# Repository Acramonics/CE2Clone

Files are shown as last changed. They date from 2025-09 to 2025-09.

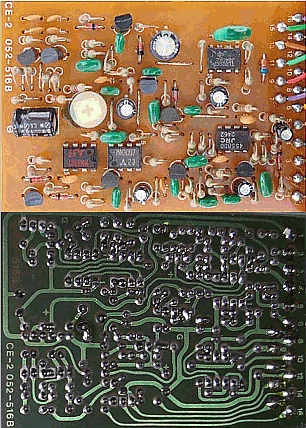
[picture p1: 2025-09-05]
Schematics/boss-ce2-board.webp

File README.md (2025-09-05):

Boss CE-2 Clone
===============

**Andrew Martin, September 2025**

*Please note that I don't yet have this working! I believe this is a result of a bad clone MN3007!*

Introduction
------------

The Boss CE-2 is one of the best-known chorus pedals around and there
have been several clones with and without modifications. In the
`Schematics` folder, there is a collection of freely-available
schematics and information while the `Analysis` folder contains some
information on chorus effects and a full analysis of the workings of
the Boss CE-2 from ElectroSmash.

The `kicad` folder contains my schematic for a clone which is
essentially the original version with the 'anti-tic' modification and
with 2N5088 transistors throughout. Within that are two sub-folders,
`V0.1` and `V1.1`. *Do not use V0.1* - this was an erroneous design
where the inputs to the RC4558 (U1) were swapped by mistake!

V1.1 is my first correct layout with (optional) LED and (bypassable)
-ve power supply resistor and diode (see some of the schamatics and
analyses for references to this). It is a very tightly packed 57x87mm
board.

V1.2 is the current version in which the PCB layout is inspired by the
one used by Azure. This one contains the (bypassable) -ve power supply
resistor and diode, but not the LED as the intention is to use it with
my FootSwitch board. This is a somewhat less tightly packed board
(73x83mm) with wider (1mm) tracks; there was notable resistance
with the narrow tracks of V1.1.

Kicad
-----

The design uses my own symbol for the 2N5088 which is in my
`ACRM_KiCad_Libs` library.

The rate and depth pots (both are 100K linear pots) are not included
in the schematic - instead there are just positions for Molex KK254
connectors. If you wish, you can omit the connectors and wire direct
to the board.

Testing
-------

Note that the MN3007/MN3101 need a negative power supply, so it is
correct that the GND pin (Pin 1) on both is connected to the +9VA rail
and the input voltage VDD pin (Pin 3 on the MN3101 and Pin 5 on the
MN3007) is connected to GND.

Faulty (apparently they are very static sensitive, but I haven't seen
that), or bad clone, MN3101s are common, so it's a good idea to check
that it's working properly. There are three things to check in the circuit:

- Connect a meter across pins 1 (your black test lead) and 3 (red test
  lead) to find the power supply voltage you are getting. This should
  be showing a value of around -8.5V. Make sure you note what the
  exact voltage is.

- Connect a meter across pins 1 (black test lead) and 8 (VGG_OUT, red
  test lead). This should read VDD*14/15, so if your VDD was -8.5, you
  should be obtaining -7.93V.

- Put a 'scope on pin 2 (CP1) and then on pin 4 (CP2). You should see
  a (roughly) square wave form that expands and contracts. The amount
  of variation changes with the depth pot and the rate with the rate
  pot.

If those tests all work, then your MN3101 is working correctly.

Setup
-----

Turn the **Rate** pot fully **anti-clockwise** (minimum rate) and the
**Depth** pot fully **clockwise** (maximum depth).

Use a signal generator to feed a 200Hz, +3dBm sine signal into the
input. This comes from the setup information I have seen online.

+3dBm is 0.893V peak-to-peak (0.316V RMS) assuming an input impedance
of 50R. However, with the 1M Rin1 input resistor, the impedance should
be closer to 1M, and that would require an input signal of >126V
peak-to-peak (44.7V RMS)!!!

I would start with 1V peak-to-peak. Connect an oscilloscope to the
emitter of Q3 and turn the bias pot (the trimmer on the board) until
you see a center point where the sine wave is symmertrical (equally
clipped at top and bottom). If you don't see any clipping, then
increase the input sine wave voltage until you do.

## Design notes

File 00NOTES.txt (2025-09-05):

BC639 (ECB) [ALL]
--or--
2N5088 (EBC)[ALL]  *
--oroo
2SC732TM-GR [Q1-Q3]
2SC945-P [Q4-Q5]

2SK30A-Y [Q9 N JFET]
1S2473/1S1588 [D1,D2,D3,D4,D5,D8] - D3 replaced with wire jumper
              D1 may be better as a 1N5817 Schottky
RD5.1EB [D6 5.1V 500mW zener]
RD11EB [D6 11V 500mW zener]

uPC4558C/JRC4558D [IC1]
TL022LP  [IC2]
MN3007   [IC3] Xvive
MN3101   [IC4] Cabintech
(Can use MN3207 / MN2102, but power reais are swapped)

Setup:
Turn the Rate knob fully counterclockwise (min.) and the Depth knob
fully clockwise (max.). Feed a 200Hz, +3dBm sine signal into the
input. Connect an oscilloscope to the emitter of Q3 and turn VR3 until
you'll get a centered operating point (a symmetrical sine wave,
equally clipped at top and bottom). 
https://www.hobby-hour.com/electronics/s/boss-ce2-chorus-schematic.php#google_vignette

https://aionfx.com/app/files/docs/azure_documentation.pdf

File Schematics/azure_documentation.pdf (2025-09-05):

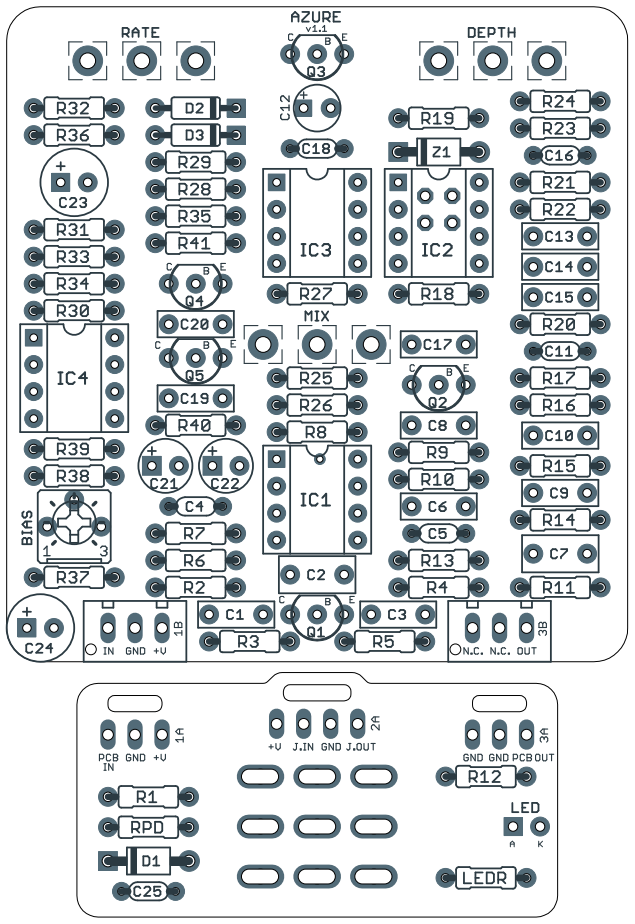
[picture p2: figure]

AZURE ANALOG CHORUS | 1

### PROJECT NAME

# AZURE (https://aionfx.com/project/azure-analog-chorus/)

### BASED ON

### EFFECT TYPE

### PROJECT SUMMARY

### DOCUMENT VERSION

## BOSS® CE-2 Chorus

One of the most revered chorus pedals of all time, it uses analog BBDs to modulate the signal, resulting in the warm, rounded tone characteristic of this era.

Analog chorus | 1.1.3 (2025-01-04) BUILD DIFFICULTY Intermediate

Actual size is 2.3” x 2.42” (main board) and 1.78” x 0.86” (bypass board).

This documentation is for the PCB-only version of the project. If you are building the full kit from Aion FX, please use the kit build documentation (https://aionfx.com/app/files/docs/azure_kit_documentation.pdf) instead. The instructions are more detailed and may differ in some areas due to the specialized parts and assembly methods used in our kits.

### IMPORTANT NOTE

AZURE ANALOG CHORUS | 2

## TABLE OF CONTENTS

1 Project Overview | 9 Drill Template
2 Introduction & Usage | 10 Enclosure Layout
3-5 Parts List | 11 Wiring Diagram
6-7 Build Notes | 12 Licensing
8 Schematic | 12 Document Revisions

## INTRODUCTION

The Azure Analog Chorus is based on the BOSS® CE-2 Chorus Ensemble, first released in 1979 and generally considered to be one of the best chorus pedals ever made. With only two knobs, it’s simple to operate, but it doesn’t take long to understand the wide range of sounds contained inside.

The CE-2B Bass Chorus followed almost a decade later in 1987. It was the same basic circuit as the CE-2, but with one component in the audio path changed to make it better suited for bass, as well as the addition of a Mix knob to blend in the wet signal.

The Azure is based on the original CE-2, but it includes the mix knob from the CE-2B. With the mix knob all the way up, it’s identical to the stock circuit, so this allows the intensity to be dialed back a bit while still preserving the originality. The full bass version can also be built with a single component substitution, covered in the parts list.

While the original CE-2 and CE-2B used the MN3007 BBD, the Azure can run on either the MN3007 or MN3207 (v3207) by setting some on-board jumpers. Since new BBD production has been slowed down significantly due to materials shortages, this flexibility makes it a little easier to find parts that will work.

## USAGE

The Azure has three controls:

- Rate sets the speed of the chorus effect.
- Depth sets the intensity of the chorus effect.
- Mix adjusts the amount of modulated signal that is blended with the clean signal to create the chorus effect. This is especially useful for bass guitar so the low-end is preserved.

AZURE ANALOG CHORUS | 3

## PARTS LIST

This parts list is also available in a spreadsheet format which can be imported directly into Mouser for easy parts ordering. Mouser doesn’t carry all the parts—notably potentiometers—so the second tab lists all the non-Mouser parts as well as sources for each.
View parts list spreadsheet (https://docs.google.com/spreadsheets/d/1Icm0P09PH_0vgAj44e0Sl8k9DHJQOHCtU8X84HcMNuA/edit?usp=sharing) →
PART VALUE | TYPE | NOTES
R1 | 1k | Metal film resistor, 1/4W
R2 | 470k | Metal film resistor, 1/4W
R3 | 10k | Metal film resistor, 1/4W
R4 | 10k | Metal film resistor, 1/4W
R5 | 47k | Metal film resistor, 1/4W
R6 | 10k | Metal film resistor, 1/4W
R7 | 47k | Metal film resistor, 1/4W
R8 | 47k | Metal film resistor, 1/4W
R9 | 47k | Metal film resistor, 1/4W
R10 | 10k | Metal film resistor, 1/4W
R11 | 470R | Metal film resistor, 1/4W
R12 | 100k | Metal film resistor, 1/4W
R13 | 100k | Metal film resistor, 1/4W
R14 | 10k | Metal film resistor, 1/4W
R15 | 10k | Metal film resistor, 1/4W
R16 | 10k | Metal film resistor, 1/4W
R17 | 10k | Metal film resistor, 1/4W
R18 | 4k7 | Metal film resistor, 1/4W
R19 | 56k | Metal film resistor, 1/4W
R20 | 330k | Metal film resistor, 1/4W
R21 | 10k | Metal film resistor, 1/4W
R22 | 10k | Metal film resistor, 1/4W
R23 | 10k | Metal film resistor, 1/4W
R24 | 10k | Metal film resistor, 1/4W
R25 | 1M | Metal film resistor, 1/4W
R26 | 47k | Metal film resistor, 1/4W
R27 | 33k | Metal film resistor, 1/4W
R28 | 2k7 | Metal film resistor, 1/4W
R29 | 150k | Metal film resistor, 1/4W
R30 | 47k | Metal film resistor, 1/4W
R31 | 33k | Metal film resistor, 1/4W
R32 | 10k | Metal film resistor, 1/4W

AZURE ANALOG CHORUS | 4

PARTS LIST, CONT.
PART VALUE | TYPE | NOTES
R33 | 1M | Metal film resistor, 1/4W
R34 | 220k | Metal film resistor, 1/4W
R35 | 4k7 | Metal film resistor, 1/4W
R36 | 4k7 | Metal film resistor, 1/4W
R37 | 4k7 | Metal film resistor, 1/4W
R38 | 4k7 | Metal film resistor, 1/4W
R39 | 10k | Metal film resistor, 1/4W
R40 | 10k | Metal film resistor, 1/4W
R41 | 33R | Metal film resistor, 1/4W
RPD | 2M2 | Metal film resistor, 1/4W | Input pulldown resistor. Can be as low as 1M.
LEDR | 10k | Metal film resistor, 1/4W | LED current-limiting resistor. Adjust value to change LED brightness.
C1 | 47n | Film capacitor, 7.2 x 2.5mm
C2 | 470n | Film capacitor, 7.2 x 3mm
C3 | 6n8 | Film capacitor, 7.2 x 2.5mm
C4 | 100pF | MLCC capacitor, NP0/C0G
C5 | 100pF | MLCC capacitor, NP0/C0G
C6 | 6n8 | Film capacitor, 7.2 x 2.5mm
C7 | 1uF | Film capacitor, 7.2 x 3.5mm
C8 | 33n | Film capacitor, 7.2 x 2.5mm
C9 | 3n3 | Film capacitor, 7.2 x 2.5mm
C10 | 8n2 | Film capacitor, 7.2 x 2.5mm
C11 | 470pF | MLCC capacitor, NP0/C0G
C12 | 1uF | Tantalum capacitor, 044A
C13 | 33n | Film capacitor, 7.2 x 2.5mm
C14 | 3n3 | Film capacitor, 7.2 x 2.5mm
C15 | 8n2 | Film capacitor, 7.2 x 2.5mm
C16 | 470pF | MLCC capacitor, NP0/C0G
C17 | 33n | Film capacitor, 7.2 x 2.5mm | CE-2B (bass version) uses 12n here.
C18 | 47pF | MLCC capacitor, NP0/C0G
C19 | 100n | Film capacitor, 7.2 x 2.5mm
C20 | 10n | Film capacitor, 7.2 x 2.5mm
C21 | 47uF | Electrolytic capacitor, 5mm | Reference voltage filter capacitor.
C22 | 47uF | Electrolytic capacitor, 5mm | Reference voltage filter capacitor.
C23 | 220uF | Electrolytic capacitor, 6.3mm | Power supply filter capacitor.
C24 | 100uF | Electrolytic capacitor, 6.3mm | Power supply filter capacitor.
C25 | 100n | MLCC capacitor, X7R | Power supply filter capacitor.
Z1 | 1N4739A | Zener diode, 9.1V, DO-41 | BBD protection diode. Use 1N4743 if using MN3007.

AZURE ANALOG CHORUS | 5

PARTS LIST, CONT.
PART | VALUE | TYPE | NOTES
D1 | 1N5817 | Schottky diode, DO-41
D2 | 1N914 | Fast-switching diode, DO-35
D3 | 1N914 | Fast-switching diode, DO-35
Q1 | 2N5088 | BJT transistor, NPN, TO-92 | Substitute. Original uses 2SC732TM-GR.
Q2 | 2N5088 | BJT transistor, NPN, TO-92 | Substitute. Original uses 2SC732TM-GR.
Q3 | 2N5088 | BJT transistor, NPN, TO-92 | Substitute. Original uses 2SC732TM-GR.
Q4 | 2N5088 | BJT transistor, NPN, TO-92 | Substitute. Original uses 2SC945P.
Q5 | 2N5088 | BJT transistor, NPN, TO-92 | Substitute. Original uses 2SC945P.
IC1 | JRC4558D | Operational amplifier, DIP8
IC1-S | DIP-8 socket IC socket, DIP-8
IC2 | MN3207 | Bucket-brigade delay, 1024 stages | The Coolaudio version of this chip is called the v3207.
IC2-S | DIP-8 socket IC socket, DIP-8
IC3 | MN3102 | Clock driver for BBD | The Coolaudio version of this chip is called the v3102.
IC3-S | DIP-8 socket IC socket, DIP-8
IC4 | TL022 | Operational amplifier, DIP8
IC4-S | DIP-8 socket IC socket, DIP-8
BIAS | 10k trimmer | Trimmer, 10%, 1/4” | Bourns 3362P or similar.
RATE | 100kB | 16mm right-angle PCB mount pot
DEPTH | 100kB | 16mm right-angle PCB mount pot
MIX | 250kC | 16mm right-angle PCB mount pot
LED | 5mm | LED, 5mm, red diffused
IN | 1/4" mono | 1/4" phone jack, closed frame | Switchcraft 111X or equivalent.
OUT | 1/4" mono | 1/4" phone jack, closed frame | Switchcraft 111X or equivalent.
DC | 2.1mm | DC jack, 2.1mm panel mount | Mouser 163-4302-E or equivalent.
FSW | 3PDT | Stomp switch, 3PDT
ENC | 125B | Enclosure, die-cast aluminum | Can also use a Hammond 1590N1.

AZURE ANALOG CHORUS | 6

## BUILD NOTES

## BBD selection

The original bucket-brigade delay chips used in the CE-2 have been discontinued for many years and old-stock chips are getting difficult to find. Fortunately, reproductions of both the MN3007 and the newer MN3207 are available along with the corresponding clock driver, and they perform just as well as the original devices in this circuit.

The original CE-2 uses the MN3007 (https://aionfx.com/component/mn3007/) (reproductions available from Xvive), while later chorus pedals such as the CE-3 use the MN3207 (reproductions available from Coolaudio as the v3207). (https://aionfx.com/component/v3207d/) The Azure project is set up to allow either type to be used by soldering two jumpers in one configuration or another.

So which should you use? The MN3207 has slightly better noise specs, but a lower maximum operating voltage. In this application, the maximum voltage doesn’t make much of a difference since we’re running it at 9V either way, so the added expense of the MN3007 probably outweighs any advantage.

## Clock selection

The MN3101 clocks are only compatible with the MN3007, and the MN3102 and v3102 clocks are only compatible with the MN3207 and v3207.

In late 2023, Cabintech made a discrete version of the MN3101 (https://cabintechglobal.com/ct3101) that acts as a drop-in replacement
in DIP-8 format. These perform just as well as the originals, so it’s recommended to use them in conjunction with the MN3007.

We do not recommend trying to source old-stock MN3101s due to the risk of fakes or damaged parts.

## Setting the jumpers

Underneath IC2, there are four jumper pads arranged in a square pattern. The MN3007 and MN3207 have their positive and negative supply pins inverted from each other, so the jumpers need to be set to route the supply voltages to the correct pins.

The underside of the PCB has a legend on the silkscreen showing which way the jumpers should be soldered. If using a MN3007, both jumpers should go horizontally. If using a MN3207 or v3207, the jumpers should go vertically.

The MN3101 and MN3102 clock drivers have the supply pins reversed internally, so these two chips are cross-compatible and IC3 does not require any of its own jumpers.

## Setting the bias by ear

The trimmer adjusts the bias voltage to get optimum performance from the BBD. Set the Depth and Mix knobs all the way up and set Rate to a low or medium speed, between 8:00 and 12:00. Start with the bias control at halfway, then adjust it up or down until you hear the strongest chorus and the least audible distortion.

BUILD NOTES, CONT.

## Setting the bias with an oscilloscope

If you’ve got an oscilloscope, you can look at the waveform and fine-tune the bias visually rather than by ear. Connect the oscilloscope to the emitter of Q3 or the left leg of R24. Use a signal generator to create a sine wave at 200 Hz, 3V peak to peak, and send this to the pedal’s input.

Set Depth and Mix all the way up and Rate somewhere between 8:00 and 12:00. Then, adjust the bias trimmer until the waveform is equally clipped on the top and bottom. The waveform is not symmetrical, so you’re looking for equal-width clipping but not necessarily equal-shape clipping.

The CE-2 service manual says to use a test signal amplitude of +3dBm, which should convert to around 900mV peak to peak. However, in prototyping with a digital signal generator, we found that the amplitude needed to be significantly higher to get enough clipping that it could be reliably adjusted, which is why we’ve recommended 3V.

The test signal is intended to be much larger than what the pedal will deal with in normal use, so the waveform will not clip like this in practice. It’s just easier to dial the symmetry this way.

## Bass mod

The CE-2B only has one component difference from the standard CE-2. The output capacitor of the effect signal, C17, has been lowered from 33n to 12n in the bass version.

This cuts the bass EQ of the effect signal somewhat so that only the upper frequencies are modulated and the lower frequencies are left untouched. In other words, bass mode has less bass while guitar mode has more bass. This prevents the low frequencies from modulating in a way that would sound out of tune or dissonant in a band setting.

## Depth/intensity mod

C18 can be changed from 47pF to 100pF to increase the maximum modulation depth or intensity.

## v1.0 error fix

We made a very minor layout change to the footswitch PCB in August 2022
and inadvertently disconnected a trace on the main board in the process. This blocks the wet signal, so if this trace is missing then the pedal will pass dry signal but will not have any chorus effect.

Only a few dozen PCBs were affected, anything shipping between August and November of 2022. If your footswitch PCB has the extended slot above the +V/I/GND/O pads indicated on the right, but it does not say “AZURE v1.1” at

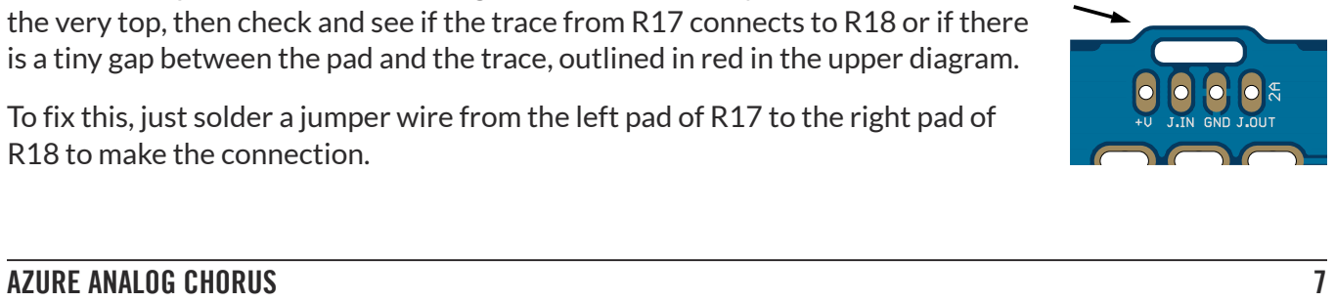
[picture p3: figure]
AZURE ANALOG CHORUS; R18 to make the connection.

the very top, then check and see if the trace from R17 connects to R18 or if there is a tiny gap between the pad and the trace, outlined in red in the upper diagram.

To fix this, just solder a jumper wire from the left pad of R17 to the right pad of

## SCHEMATIC

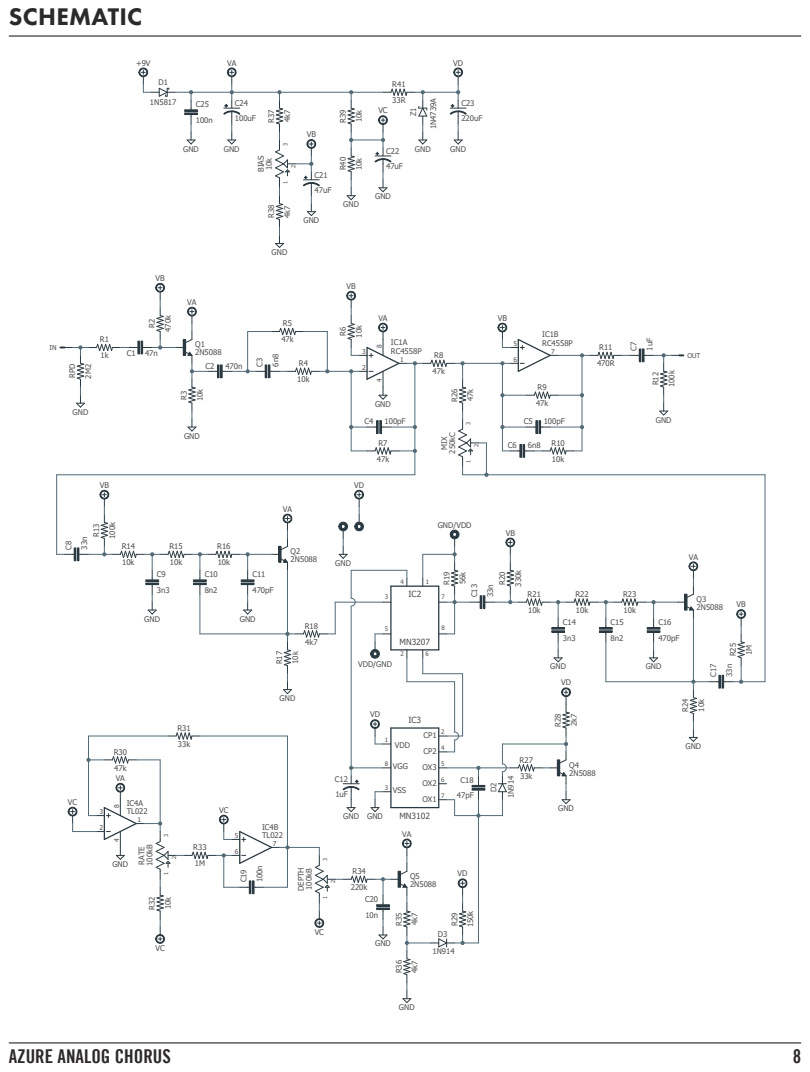
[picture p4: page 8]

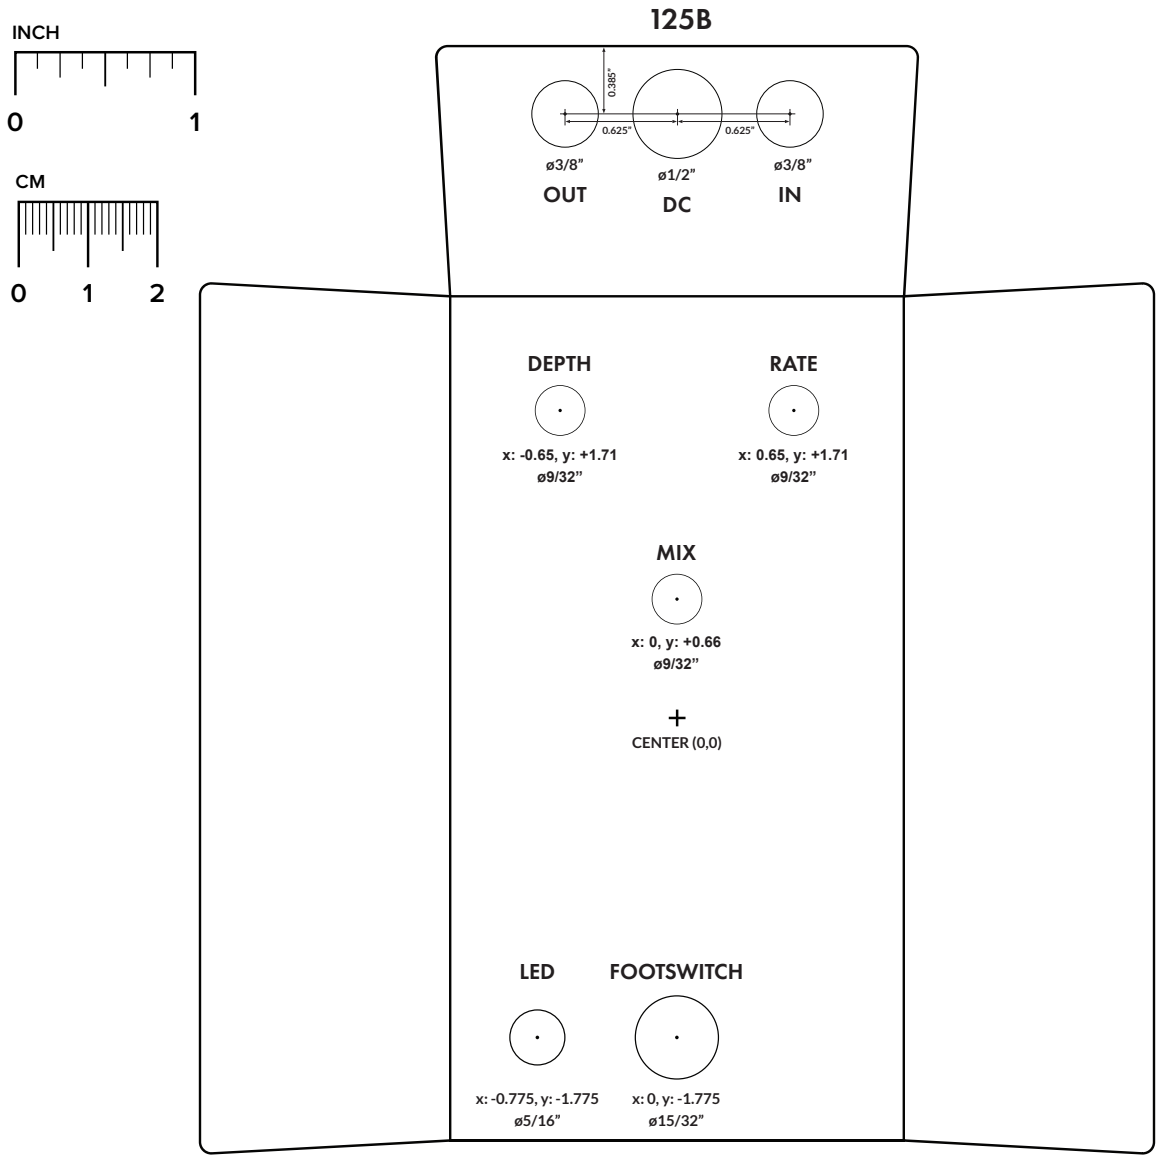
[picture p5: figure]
OUT; DEPTH; RATE; MIX; LED; FOOTSWITCH; CENTER (0,0); INCH

AZURE ANALOG CHORUS | 9

## DRILL TEMPLATE

Cut out this drill template, fold the edges and tape it to the enclosure. Before drilling, it’s recommended to first use a center punch for each of the holes to help guide the drill bit.

Ensure that this template is printed at 100% or “Actual Size”. You can double-check this by measuring the scale on the printed page.

Top jack layout assumes the use of closed-frame jacks like the Switchcraft 111X. (https://aionfx.com/link/switchcraft-111/) If you’d rather use open-frame jacks, please refer to the Open-Frame Jack Drill Template (https://aionfx.com/link/open-frame-drill-template/) for the top side.

LED hole drill size assumes the use of a 5mm LED bezel, (https://aionfx.com/link/chrome-bezel-for-5mm-led/) available from several parts suppliers. Adjust size accordingly if using something different, such as a 3mm bezel, a plastic bezel, or just a plain LED.

## ENCLOSURE LAYOUT

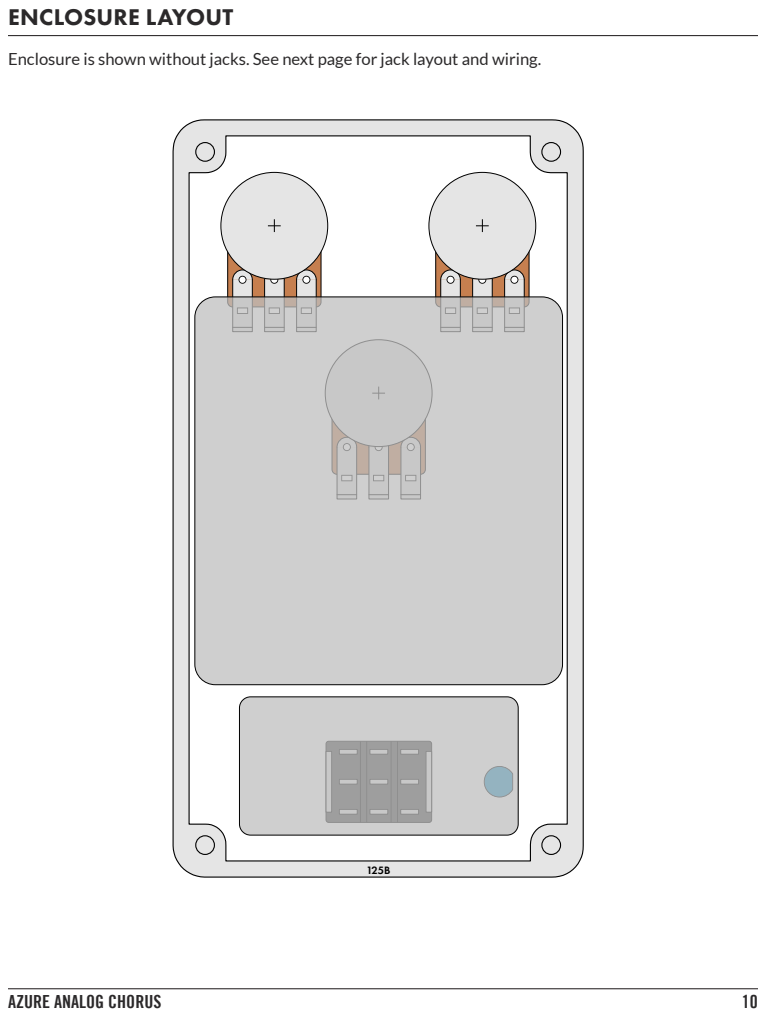
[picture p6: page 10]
AZURE ANALOG CHORUS

Enclosure is shown without jacks. See next page for jack layout and wiring.

## WIRING DIAGRAM

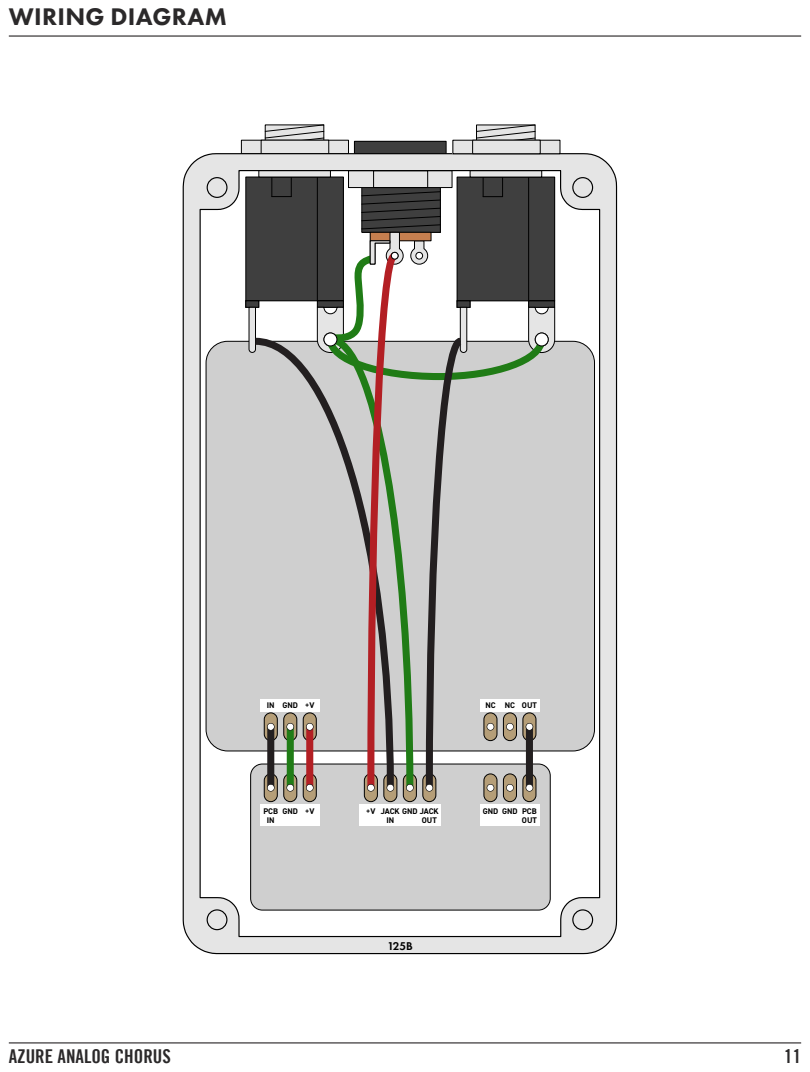
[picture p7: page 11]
AZURE ANALOG CHORUS; IN GND +V; NC NC OUT; PCB IN; GND +V; +V JACK GND JACK; OUT

GND GND PCB

AZURE ANALOG CHORUS | 12

## LICENSE & USAGE

No direct support is offered for these projects beyond the provided documentation. It’s assumed that you have at least some experience building pedals before starting one of these. Replacements and refunds cannotbe offered unless it can be shown that the circuit or documentation are in error.

All of these circuits have been tested in good faith in their base configurations. However, not all the modifications or variations have necessarily been tested. These are offered only as suggestions based on the experience and opinions of others.

Projects may be used for commercial endeavors in any quantity unless specifically noted. No attribution is necessary, though a link back is always greatly appreciated. The only usage restrictions are that (1) you cannot resell the PCB as part of a kit without prior arrangement, and (2) you cannot “goop” the circuit, scratch off the screenprint, or otherwise obfuscate the circuit to disguise its source. (In other words: you don’t have to go out of your way to advertise the fact that you use these PCBs, but please don’t go out of your way to hide it. The guitar effects industry needs more transparency, not less!)

## DOCUMENT REVISIONS

1.1.3 (2025-01-04)
Minor revisions to the biasing procedure on pages 6-7.

1.1.2 (2024-08-08)
Changed LEDR to 10k to work with a wider variety of LEDs.

1.1.1 (2023-12-07)
Added RPD, R1 and R12 to the schematic. They were present on the PCB and parts list but the schematic omitted them.

1.1.0 (2022-12-08)
Error fix for approximately 40 PCBs that shipped between August and November 2022.

1.0.1 (2022-01-25)
Updated Z1 in schematic to 1N4739A (was 1N4738A). The parts list was correct.

1.0.0 (2021-11-26)
Initial release.

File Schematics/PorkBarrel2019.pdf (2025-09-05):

# Pork Barrel 2019

### FX TYPE: Modulation

Based on the Boss® CE-2™

### New for 2019

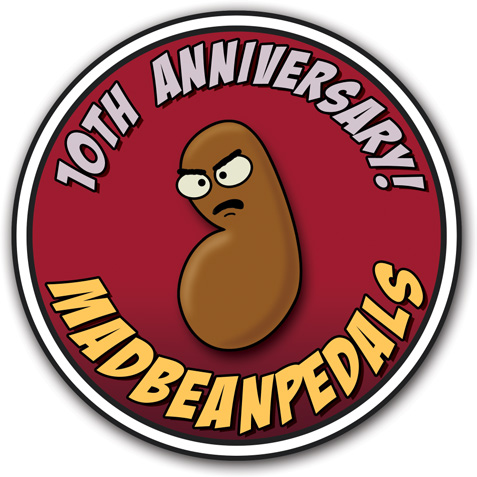
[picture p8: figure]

The 2019 version is the same basic circuit as before but has an optional Blend control added. This control allows you to blend between dry, chorus and vibrato effects. The Blend control is implemented with minimal modification in mind. If you want to build a traditional CE-2 only, simply omit the Blend pot. Not other changes are necessary.

### Overview

The Pork Barrel is a clone of the classic Boss® CE-2™. The CE-2™ has a signature sound and been a staple of many guitar and bass pedal boards for decades. Next to the EHX Small Clone, it is one of the most instantly recognizable chorus effects out there. Even if you don’t like chorus, this is one of the best analog ones ever made.
The Pork Barrel is designed to utilize several different BBD types depending on availability and price. Minimal modifications are required to set the build up for these different BBDs, and this will be explained in detail later on in this document.

### Controls

- RATE: Chorus speed from slow to fast.
- DEPTH: Chorus depth from min to max.
- BLEND: Mix of dry, chorus and vibrato. CCW is dry (no modulation), 1/4 up to middle is chorus and fully CW is vibrato.
- T1: Sets he bias of the chorus effect.

Terms of Use: You are free to use purchased Pork Barrel circuit boards for both DIY and small commercial operations. You may not offer Pork Barrel PCBs for resale or as part of a “kit” in a commercial fashion. Peer to peer re-sale is fine, though.

### Layout &Traces

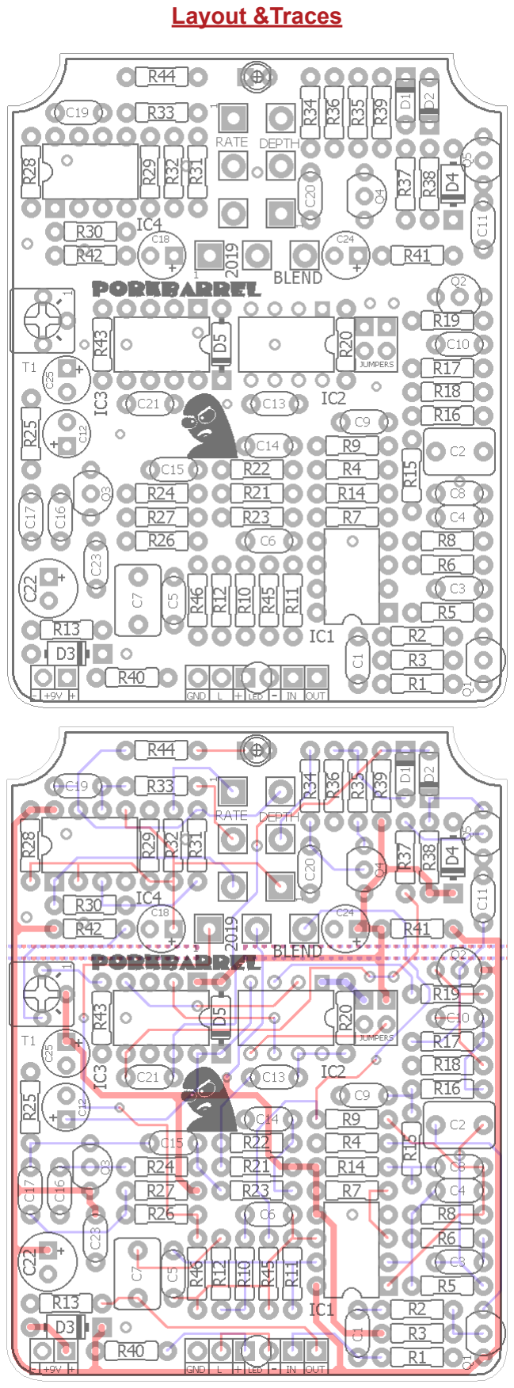
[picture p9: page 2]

B.O.M.

Resistors | Resistors | Caps | Diodes
R1 | 1M | R31 | 33k | C1 | 47n | D1 | 1n914
R2 | 1k | R32 | 10k | C2 | 1uF | D2 | 1n914
R3 | 470k | R33 | 1M | C3 | 6n8 | D3 | 1N5817
R4 | 10k | R34 | 220k | C4 | 100pF | D4 | *see notes
R5 | 47k | R35 | 4k7 | C5 | 100pF | D5 | omit
R6 | 10k | R36 | 4k7 | C6 | 6n8 | Transistors
R7 | 10k | R37 | 33k | C7 | 1uF | Q1 - Q5 | 2N5088
R8 | 47k | R38 | 2k7 | C8 | 33n | | IC
R9 | 27k | R39 | 150k | C9 | 3n3 | IC1 | 4558
R10 | 10k | R40 | 4k7 | C10 | 8n2 | IC2 | BBD
R11 | 47k | R41 | 33R | C11 | 470pF | IC3 | CLOCK
R12 | 470R | R42 | 4k7 | C12 | 1uF | IC4 | TL062
R13 | 100k | R43 | 4k7 | C13 | 33n | Trimmer
R14 | 100k | R44 | 10k | C14 | 3n3 | T1 | 10k
R15 | 10k | R45 | 20k | C15 | 8n2 | Pots
R16 | 10k | R46 | 20k | C16 | 470pF | DEPTH | 100kB
R17 | 10k | | | C17 | 33n | RATE | 100kB
R18 | 10k | | | C18 | 47uF | BLEND | 50kC
R19 | 4k7 | | | C19 | 100n
R20 | 56k | | | C20 | 10n
R21 | 330k | | | C21 | 47pF
R22 | 10k | | | C22 | 100uF
R23 | 10k | | | C23 | 100n
R24 | 10k | | | C24 | 47uF
R25 | 10k | | | C25 | 47uF
R26 | 27k
R27 | 1M
R28 | 10k
R29 | 10k
R30 | 47k

### Shopping List

Value | QTY | Type | Rating
33R | 1 | Metal / Carbon Film | 1/4W
470R | 1 | Metal / Carbon Film | 1/4W
1k | 1 | Metal / Carbon Film | 1/4W
2k7 | 1 | Metal / Carbon Film | 1/4W
4k7 | 6 | Metal / Carbon Film | 1/4W
10k | 16 | Metal / Carbon Film | 1/4W
20k | 2 | Metal / Carbon Film | 1/4W
27k | 2 | Metal / Carbon Film | 1/4W
33k | 2 | Metal / Carbon Film | 1/4W
47k | 4 | Metal / Carbon Film | 1/4W
56k | 1 | Metal / Carbon Film | 1/4W
100k | 2 | Metal / Carbon Film | 1/4W
150k | 1 | Metal / Carbon Film | 1/4W
220k | 1 | Metal / Carbon Film | 1/4W
330k | 1 | Metal / Carbon Film | 1/4W
470k | 1 | Metal / Carbon Film | 1/4W
1M | 3 | Metal / Carbon Film | 1/4W
47pF | 1 | MLCC / MICA | 25v min.
100pF | 2 | Ceramic / MLCC | 25v min.
470pF | 2 | Ceramic / MLCC | 25v min.
3n3 | 2 | Film | 25v min.
6n8 | 2 | Film | 25v min.
8n2 | 2 | Film | 25v min.
10n | 1 | Film | 25v min.
33n | 3 | Film | 25v min.
47n | 1 | Film | 25v min.
100n | 2 | Film | 25v min.
1uF | 2 | Film | 25v min.
1uF | 1 | Electrolytic | 25v min.
47uF | 3 | Electrolytic | 25v min.
100uF | 1 | Electrolytic | 25v min.
1n914 | 2
1N5817 1
Zener | 1 | *see notes
2N5088 5
4558 | 1
BBD | 1 | *see notes
CLOCK 1 | *see notes
TL062 | 1
10k | 1 | Bourns 3362p
100kB | 2 Right Angle, PCB Mount 16mm
50kC | 1 Right Angle, PCB Mount 16mm

### Parts Guide

9.1v Zener:
http://smallbear-electronics.mybigcommerce.com/diode-zener-1n4739a/12v Zener:
http://smallbear-electronics.mybigcommerce.com/diode-zener-1n4742a/MN3007:
http://smallbear-electronics.mybigcommerce.com/ic-mn3007/
MN3101 (currently out of stock): http://smallbear-electronics.mybigcommerce.com/ic-mn3101/BL3207:
http://smallbear-electronics.mybigcommerce.com/ic-bl3207/BL3102:
http://smallbear-electronics.mybigcommerce.com/ic-bl3102/v3207:
http://smallbear-electronics.mybigcommerce.com/ic-v3207d/v32012:
http://smallbear-electronics.mybigcommerce.com/ic-v3102d/TL062:
http://smallbear-electronics.mybigcommerce.com/ic-tl062/
Bourns 10k trimpot:
https://www.mouser.com/ProductDetail/Bourns/3362P-1-103LF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 (https://www.mouser.com/ProductDetail/Bourns/3362P-1-103LF)

https://www.taydaelectronics.com/potentiometer-variable-resistors/cermet-potentiometers/3362p/10k-ohm-trimmer-potentiometer-cermet-1-turn-3362p.html (https://www.taydaelectronics.com/potentiometer-variable-resistors/cermet-potentiometers/3362p/10k-ohm-trimmer-potentiometer-cermet-1-turn-3362p.html)
16mm PCB Mount pots:
http://smallbear-electronics.mybigcommerce.com/alpha-single-gang-16mm-right-angle-pc-mount/
DC Jack:
http://smallbear-electronics.mybigcommerce.com/dc-power-jack-all-plastic-unswitched-2-1-mm/ Lumberg Audio Jack:
http://smallbear-electronics.mybigcommerce.com/lumberg-1-4-compact-shrouded-mono-jack/

### Notes

What are the advantages of the different BBDs?

The vintage unit used the MN3007. You can safely use 9 – 12v DC to power the effect, with the higher voltage providing a small amount of additional headroom. Note that if you use 12v, you will want it to be well regulated either by your power supply, or by using a charge pump like the Road Rage. Anything over 12v will not work for this design. It may be possible to mod the circuit for 15v operation but I’ve never tried it so I cannot advise on what exactly to change.

The MN3207, v3207 and BL3207 have lower current requirements, are less expensive and easier to source. These BBDs should not be operated at higher than 9vDC. IMO, there is little to no difference in the different BBD types for the CE-2™. BBD Chart

These are the combinations of BBD and clocks you can use when building the Pork Barrel.

Jumpers

You must set one pair of jumpers on the Pork Barrel PCB to correspond to the type of BBD you are using. These jumpers determine which pins get power and ground, and sets R20 to be a pull-up or pull-down resistor.

MN3007 | MN3207, v3207, BL3207

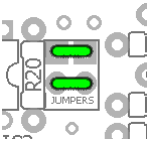
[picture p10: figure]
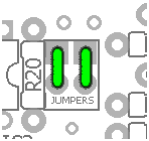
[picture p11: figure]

Biasing

Biasing the Pork Barrel is very straight forward. Set your Rate knob to its midpoint and the Depth knob to maximum. Adjust the T1 trimmer until you get the maximum chorus effect with minimal distortion. That’s it!
Blend Pot

You can omit the Blend control by simply not soldering in the pot. This gives you chorus only and is exactly like the previous versions of the Pork Barrel.
Speed Mod

Because the CE-2 was not designed to be a vibrato, its overall speed range is not ideal for that type of effect (assuming you like really fast vibrato). You can modify the LFO to get a much faster max speed but it comes with the caveat of shifting the slowest speed forward as well. If you want to try different speed ranges, socket R33. Try a 470k or 680k there (lower values means faster speeds). Check the new range with both the Chorus and Vibrato settings on the Blend pot to see if you like it. FYI: a different way to modify the range is leave R33 at 1M and change C19 to 82n or 68n.

IC2 (BBD) | IC3 (Clock) | Zener (D4) | Max Power
MN3007 | MN3101 | 12v or 15v | 12v
MN3207 | MN3102 | 9.1v | 9v
BL3207 | BL3102 | 9.1v | 9v
v3207 | v3102 | 9.1v | 9v

### Wiring

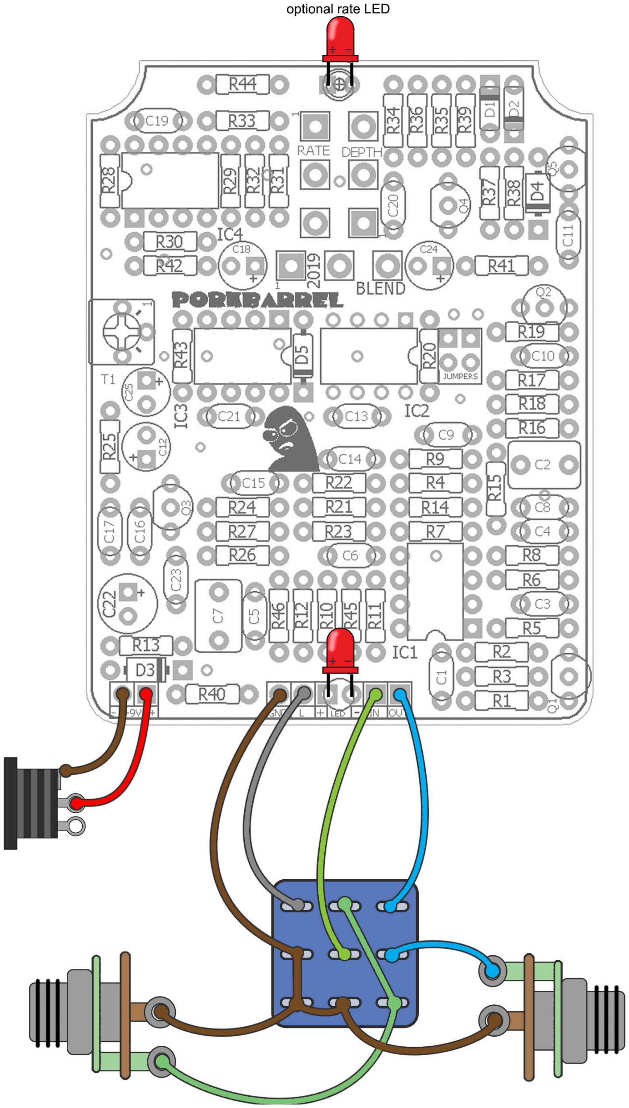
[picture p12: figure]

### 1590B Drill Guide

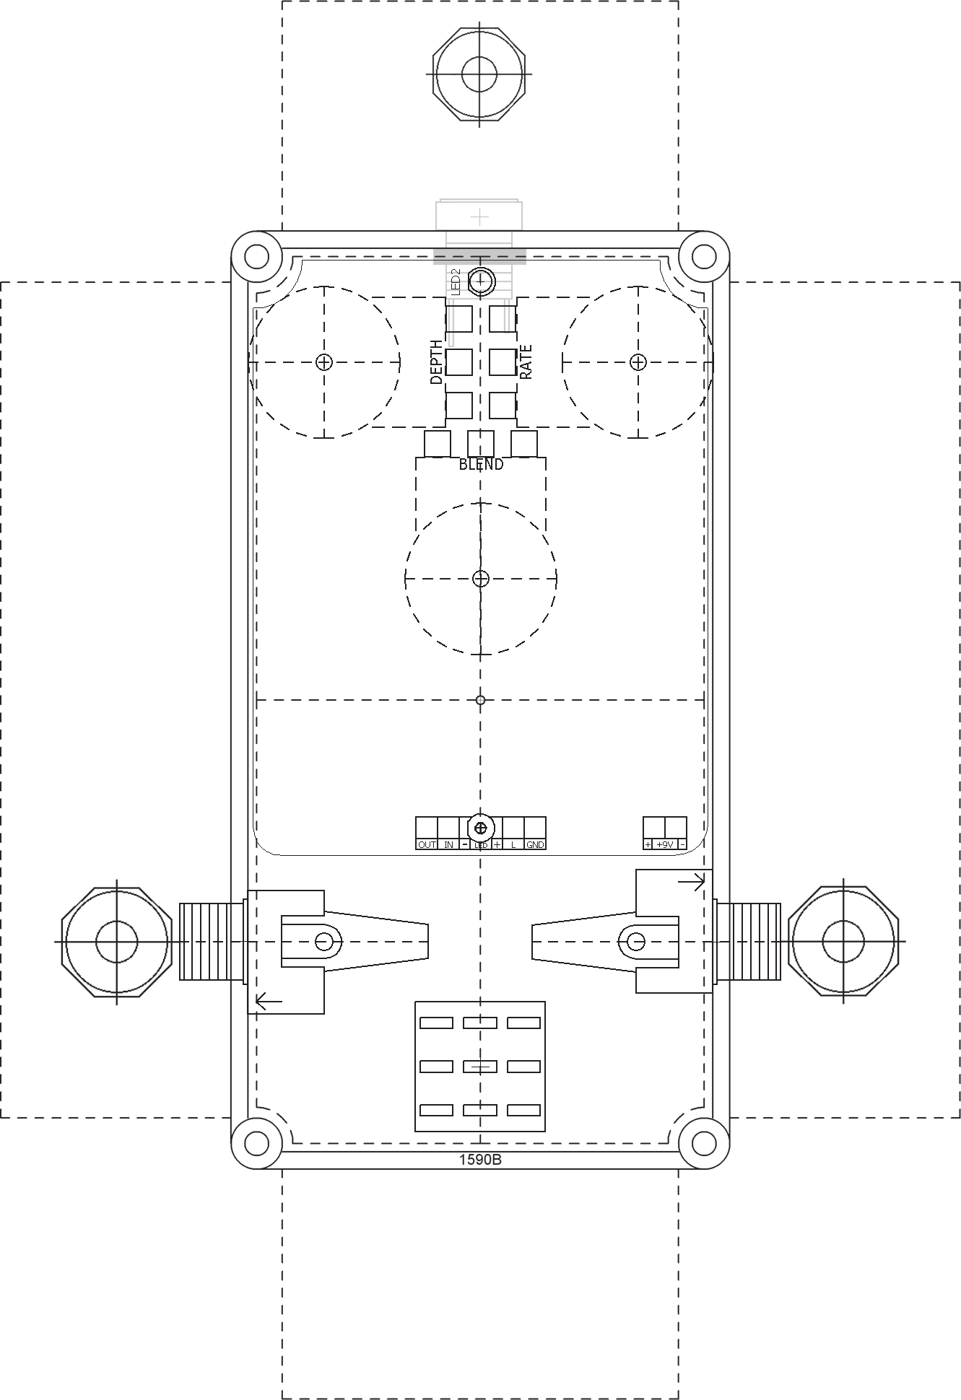
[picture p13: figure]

### I recommend using the smaller Lumberg style jacks for the input, output and DC jacks on this build. It’s a tight fit in the

1590B.

### Build Pic

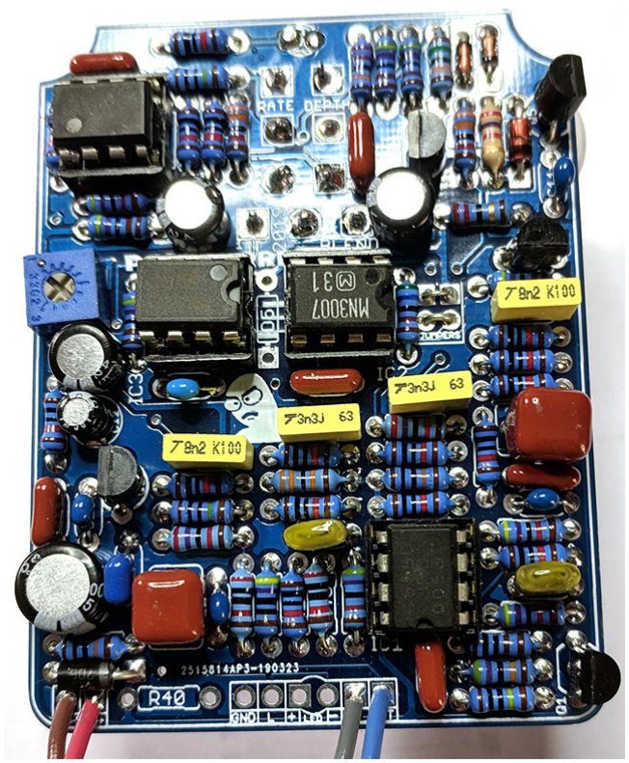
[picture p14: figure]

### This is at least my 5th Pork Barrel build and maybe 7th or 8th

CE-2 overall.

### Voltages

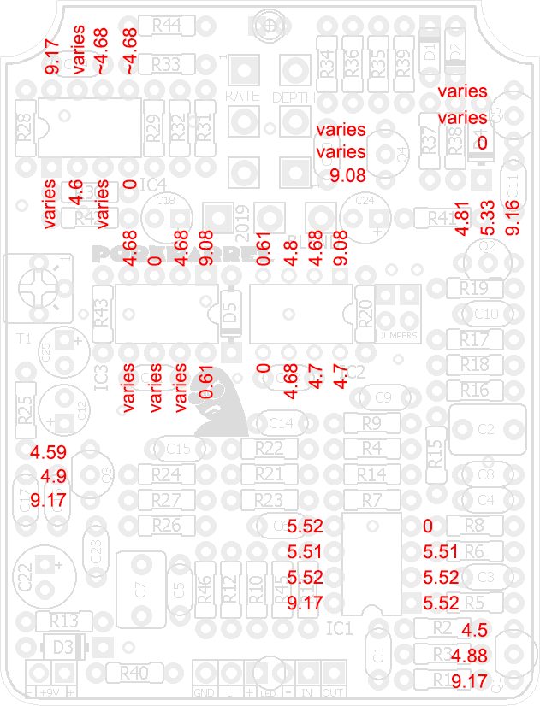
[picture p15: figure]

### 9.42v One Spot - Current Draw: 8mA

Some voltages on IC1 will vary depending on where T1 is set.

### Schematic

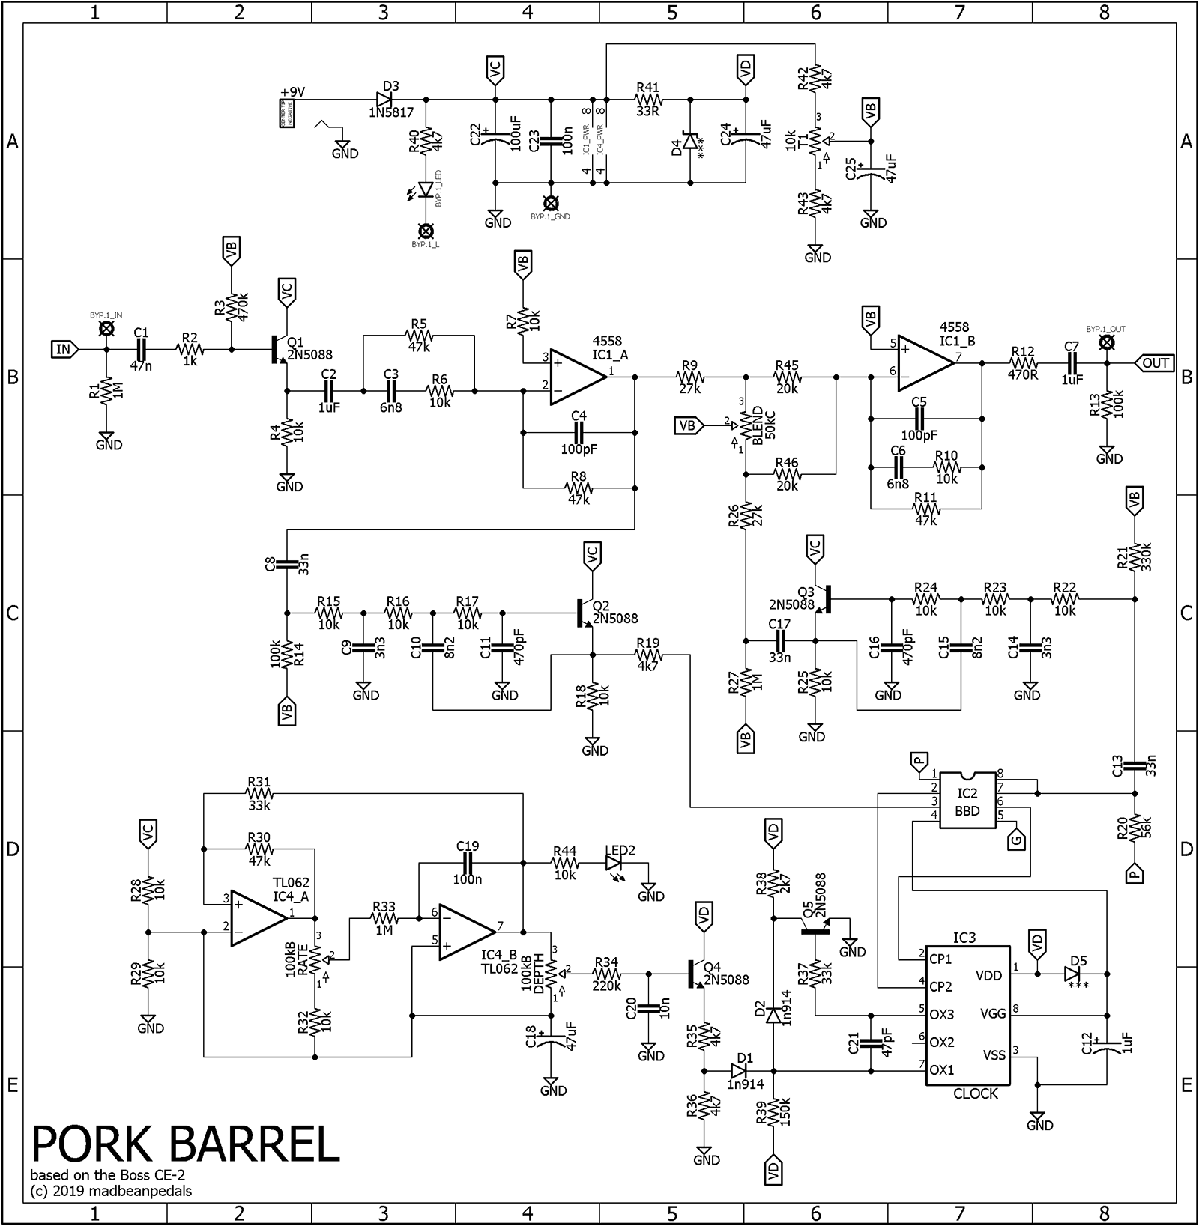
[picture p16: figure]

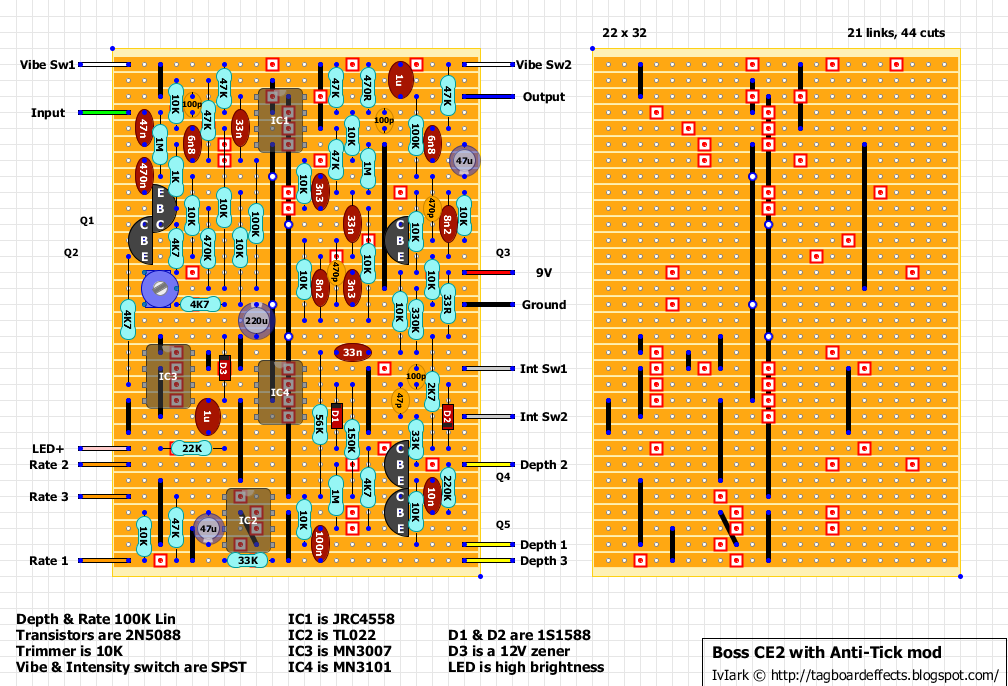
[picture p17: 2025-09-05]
Schematics/Boss CE2 with Anti-Tick Mod.png

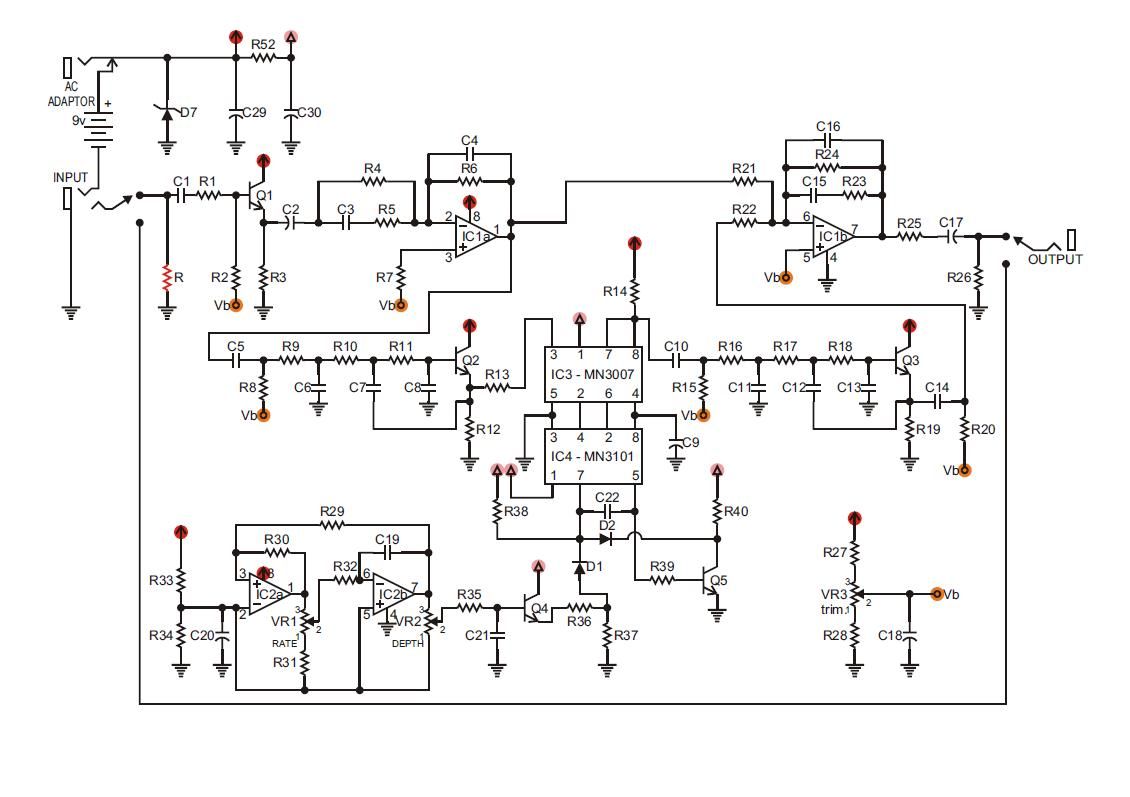
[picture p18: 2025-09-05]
Schematics/Boss_CE-2-1.jpg

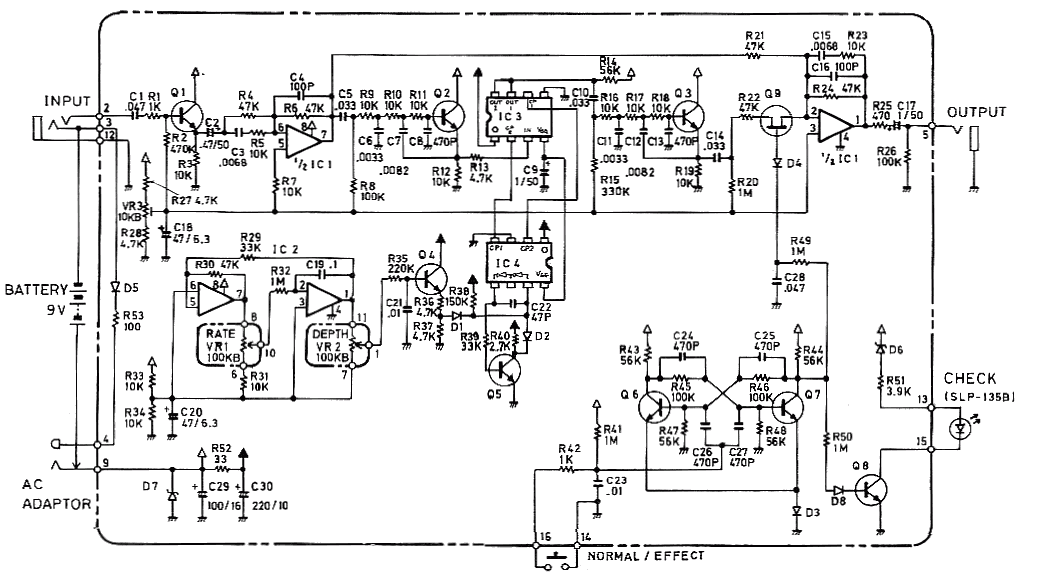
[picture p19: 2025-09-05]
Schematics/boss-ce2-chorus-schematic.webp

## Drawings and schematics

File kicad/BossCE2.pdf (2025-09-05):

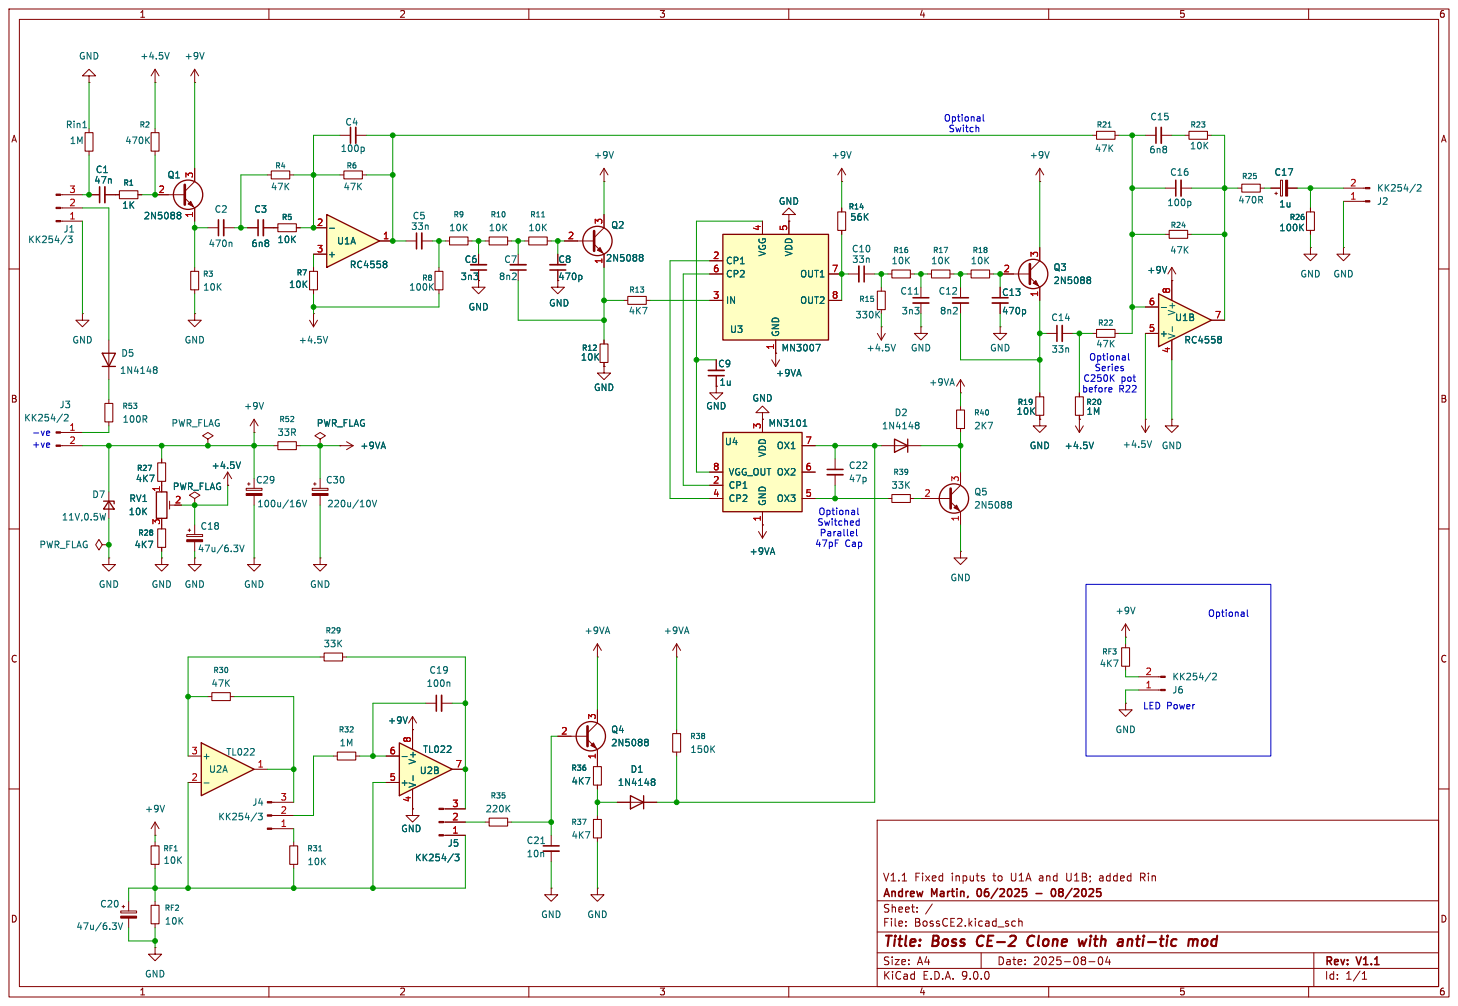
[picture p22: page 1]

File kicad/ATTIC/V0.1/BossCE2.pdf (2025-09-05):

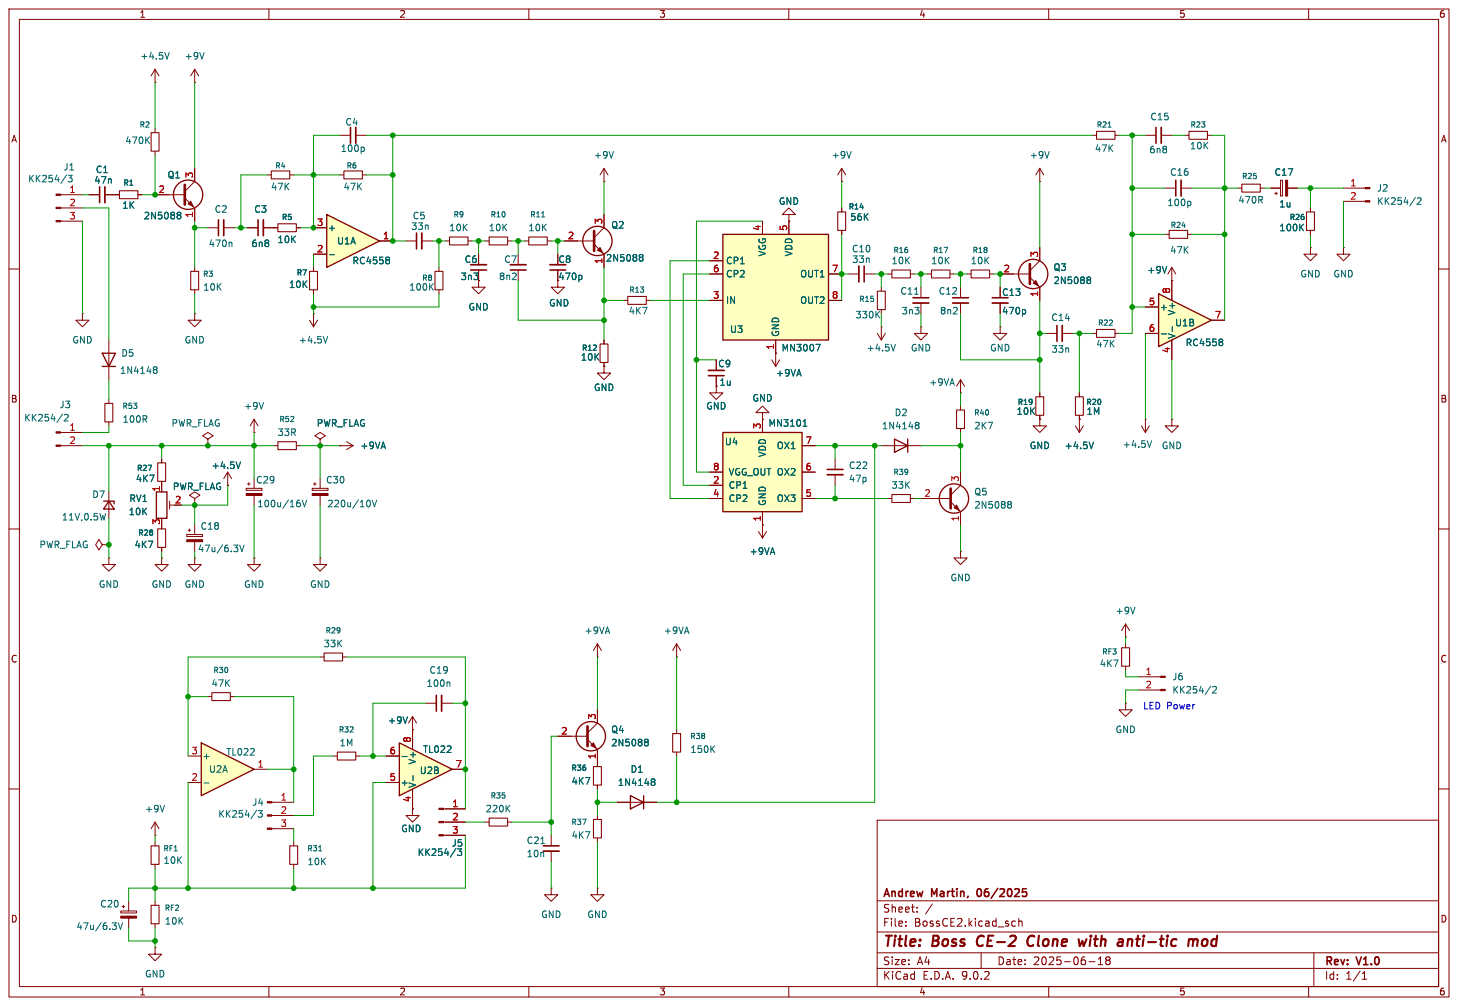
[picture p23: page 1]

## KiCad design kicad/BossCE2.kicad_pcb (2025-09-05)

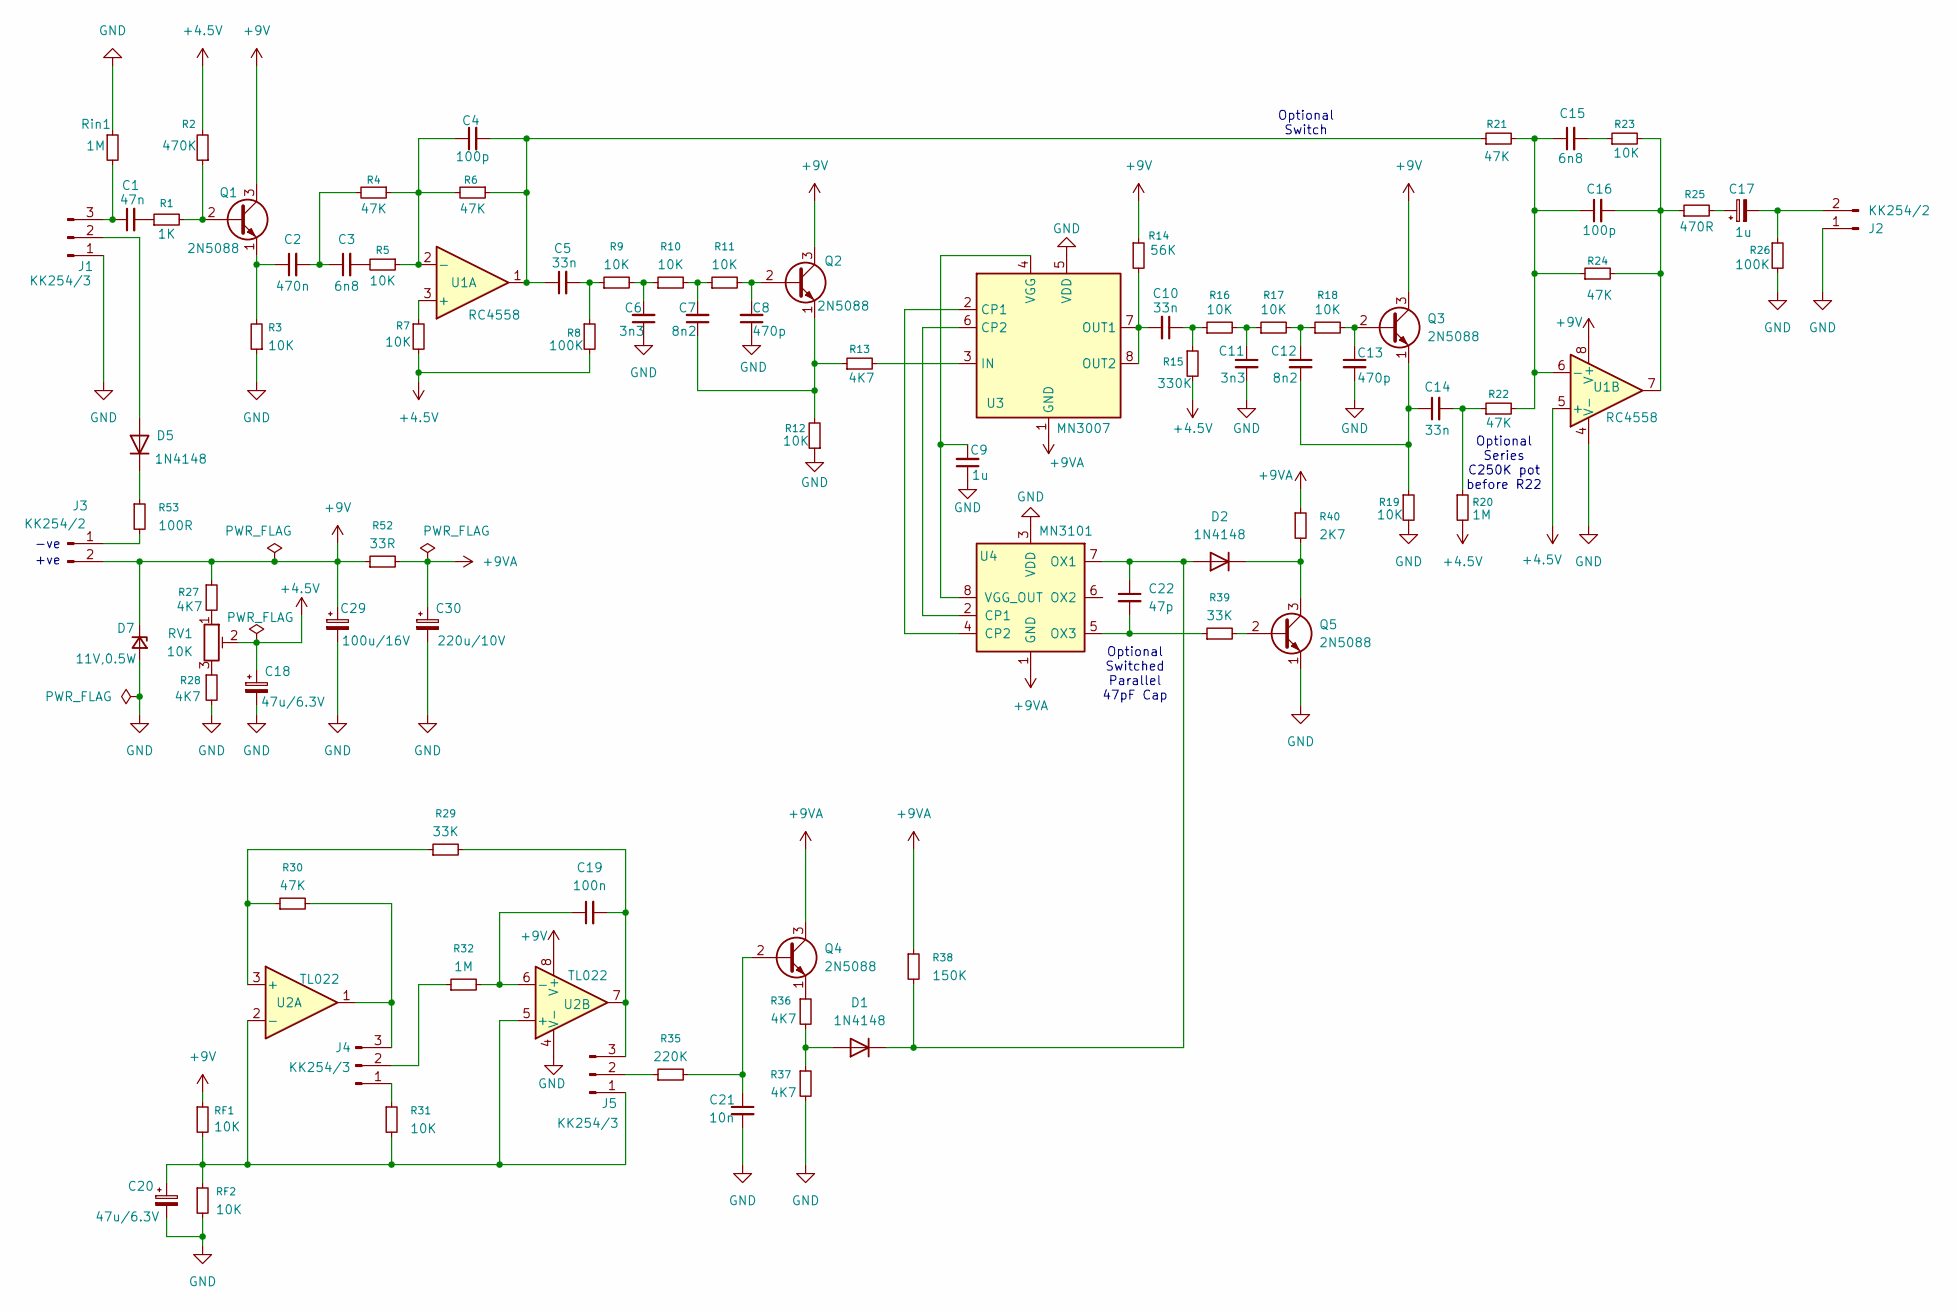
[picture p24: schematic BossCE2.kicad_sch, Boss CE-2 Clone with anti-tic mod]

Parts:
C1: 47n; C_Rect_L7.0mm_W2.5mm_P5.00mm
C2: 470n; C_Rect_L7.0mm_W2.5mm_P5.00mm
C3, C15: 6n8; C_Rect_L7.0mm_W2.5mm_P5.00mm
C4, C16: 100p; C_Disc_D4.3mm_W1.9mm_P5.00mm
C5, C10, C14: 33n; C_Rect_L7.0mm_W2.5mm_P5.00mm
C6, C11: 3n3; C_Rect_L7.0mm_W2.5mm_P5.00mm
C7, C12: 8n2; C_Rect_L7.0mm_W2.5mm_P5.00mm
C8, C13: 470p; C_Disc_D4.3mm_W1.9mm_P5.00mm
C9, C17: 1u; C_Rect_L7.0mm_W2.5mm_P5.00mm
C18, C20: 47u/6.3V; CP_Radial_D5.0mm_P2.50mm
C19: 100n; C_Rect_L7.0mm_W2.5mm_P5.00mm
C21: 10n; C_Disc_D4.3mm_W1.9mm_P5.00mm
C22: 47p; C_Disc_D4.3mm_W1.9mm_P5.00mm
C29: 100u/16V; CP_Radial_D5.0mm_P2.50mm
C30: 220u/10V; CP_Radial_D5.0mm_P2.50mm
D1, D2, D5: 1N4148; D_DO-35_SOD27_P7.62mm_Horizontal
D7: 11V,0.5W; D_DO-35_SOD27_P7.62mm_Horizontal
J1, J4, J5: KK254/3; Molex_KK-254_AE-6410-03A_1x03_P2.54mm_Vertical
J2, J3: KK254/2; Molex_KK-254_AE-6410-02A_1x02_P2.54mm_Vertical
Q1, Q2, Q3, Q4, Q5: 2N5088; TO-92L_HandSolder
R1: 1K; R_Axial_DIN0207_L6.3mm_D2.5mm_P10.16mm_Horizontal
R2: 470K; R_Axial_DIN0207_L6.3mm_D2.5mm_P10.16mm_Horizontal
R3, R5, R7, R9, R10, R11, R12, R16, R17, R18, R19, R23, R31: 10K; R_Axial_DIN0207_L6.3mm_D2.5mm_P10.16mm_Horizontal
R4, R6, R21, R22, R24, R30: 47K; R_Axial_DIN0207_L6.3mm_D2.5mm_P10.16mm_Horizontal
R8, R26: 100K; R_Axial_DIN0207_L6.3mm_D2.5mm_P10.16mm_Horizontal
R13, R27, R28, R36, R37: 4K7; R_Axial_DIN0207_L6.3mm_D2.5mm_P10.16mm_Horizontal
R14: 56K; R_Axial_DIN0207_L6.3mm_D2.5mm_P10.16mm_Horizontal
R15: 330K; R_Axial_DIN0207_L6.3mm_D2.5mm_P10.16mm_Horizontal
R20, R32: 1M; R_Axial_DIN0207_L6.3mm_D2.5mm_P10.16mm_Horizontal
R25: 470R; R_Axial_DIN0207_L6.3mm_D2.5mm_P10.16mm_Horizontal
R29, R39: 33K; R_Axial_DIN0207_L6.3mm_D2.5mm_P10.16mm_Horizontal
R35: 220K; R_Axial_DIN0207_L6.3mm_D2.5mm_P10.16mm_Horizontal
R38: 150K; R_Axial_DIN0207_L6.3mm_D2.5mm_P10.16mm_Horizontal
R40: 2K7; R_Axial_DIN0207_L6.3mm_D2.5mm_P10.16mm_Horizontal
R52: 33R; R_Axial_DIN0207_L6.3mm_D2.5mm_P10.16mm_Horizontal
R53: 100R; R_Axial_DIN0207_L6.3mm_D2.5mm_P10.16mm_Horizontal
RF1, RF2: 10K; R_Axial_DIN0207_L6.3mm_D2.5mm_P10.16mm_Horizontal
RV1: 10K; Potentiometer_Piher_PT-10-V05_Vertical
Rin1: 1M; R_Axial_DIN0207_L6.3mm_D2.5mm_P10.16mm_Horizontal
U1: RC4558; DIP-8_W7.62mm
U2: TL022; DIP-8_W7.62mm
U3: MN3007; DIP-8_W7.62mm
U4: MN3101; DIP-8_W7.62mm

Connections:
+4.5V: C18.1, R2.2, R7.2, R8.2, R15.2, R20.2, RV1.2, U1.5 (+)
+9V: C29.1, D7.1 (K), J3.2, Q1.3 (C), Q2.3 (C), Q3.3 (C), R14.1, R27.1, R52.1, RF1.1, U1.8 (V+), U2.8 (V+)
+9VA: C30.1, Q4.3 (C), R38.1, R40.1, R52.2, U3.1 (GND), U4.1 (GND)
GND: C6.1, C8.1, C9.1, C11.2, C13.2, C18.2, C20.2, C21.2, C29.2, C30.2, D7.2 (A), J1.1, J2.1, Q5.1 (E), R3.1, R12.1, R19.2, R26.2, R28.2, R37.2, RF2.2, Rin1.1, U1.4 (V-), U2.4 (V-), U3.5 (VDD), U4.3 (VDD)
unnamed: C1.2, R1.1
unnamed: C2.2, C3.1, R4.2
unnamed: C3.2, R5.2
unnamed: C4.2, C5.1, R6.1, R21.1, U1.1
unnamed: C5.2, R8.1, R9.1
unnamed: C6.2, R9.2, R10.1
unnamed: C7.2, R10.2, R11.1
unnamed: C10.1, R15.1, R16.1
unnamed: C11.1, R16.2, R17.1
unnamed: C12.1, R17.2, R18.1
unnamed: C14.2, R20.1, R22.1
unnamed: C15.2, R23.1
unnamed: C16.2, R23.2, R24.2, R25.1, U1.7
unnamed: C17.1, R25.2
unnamed: D1.2 (A), R36.2, R37.1
unnamed: C22.1, D1.1 (K), D2.2 (A), R38.2, U4.7 (OX1)
unnamed: D2.1 (K), Q5.3 (C), R40.2
unnamed: D5.2 (A), J1.2
unnamed: D5.1 (K), R53.1
unnamed: C1.1, J1.3, Rin1.2
unnamed: C17.2, J2.2, R26.1
unnamed: J3.1, R53.2
unnamed: J4.1, R31.1
unnamed: J4.2, R32.1
unnamed: J4.3, R30.2, U2.1
unnamed: C20.1, J5.1, R31.2, RF1.2, RF2.1, U2.2 (-), U2.5 (+)
unnamed: J5.2, R35.1
unnamed: C19.2, J5.3, R29.2, U2.7
unnamed: Q1.2 (B), R1.2, R2.1
unnamed: C2.1, Q1.1 (E), R3.2
unnamed: C8.2, Q2.2 (B), R11.2
unnamed: C7.1, Q2.1 (E), R12.2, R13.1
unnamed: C13.1, Q3.2 (B), R18.2
unnamed: C12.2, C14.1, Q3.1 (E), R19.1
unnamed: C21.1, Q4.2 (B), R35.2
unnamed: Q4.1 (E), R36.1
unnamed: Q5.2 (B), R39.2
unnamed: R27.2, RV1.1
unnamed: R28.1, RV1.3
unnamed: R7.1, U1.3 (+)
unnamed: C4.1, R4.1, R5.1, R6.2, U1.2 (-)
unnamed: C15.1, C16.1, R21.2, R22.2, R24.1, U1.6 (-)
unnamed: R29.1, R30.1, U2.3 (+)
unnamed: C19.1, R32.2, U2.6 (-)
unnamed: U3.2 (CP1), U4.4 (CP2)
unnamed: U3.6 (CP2), U4.2 (CP1)
unnamed: R13.2, U3.3 (IN)
unnamed: C10.2, R14.2, U3.7 (OUT1), U3.8 (OUT2)
unnamed: C9.2, U3.4 (VGG), U4.8 (VGG_OUT)
unnamed: C22.2, R39.1, U4.5 (OX3)

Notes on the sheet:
+ve
Optional Series C250K pot before R22
Optional Switched Parallel 47pF Cap
Optional Switch
-ve

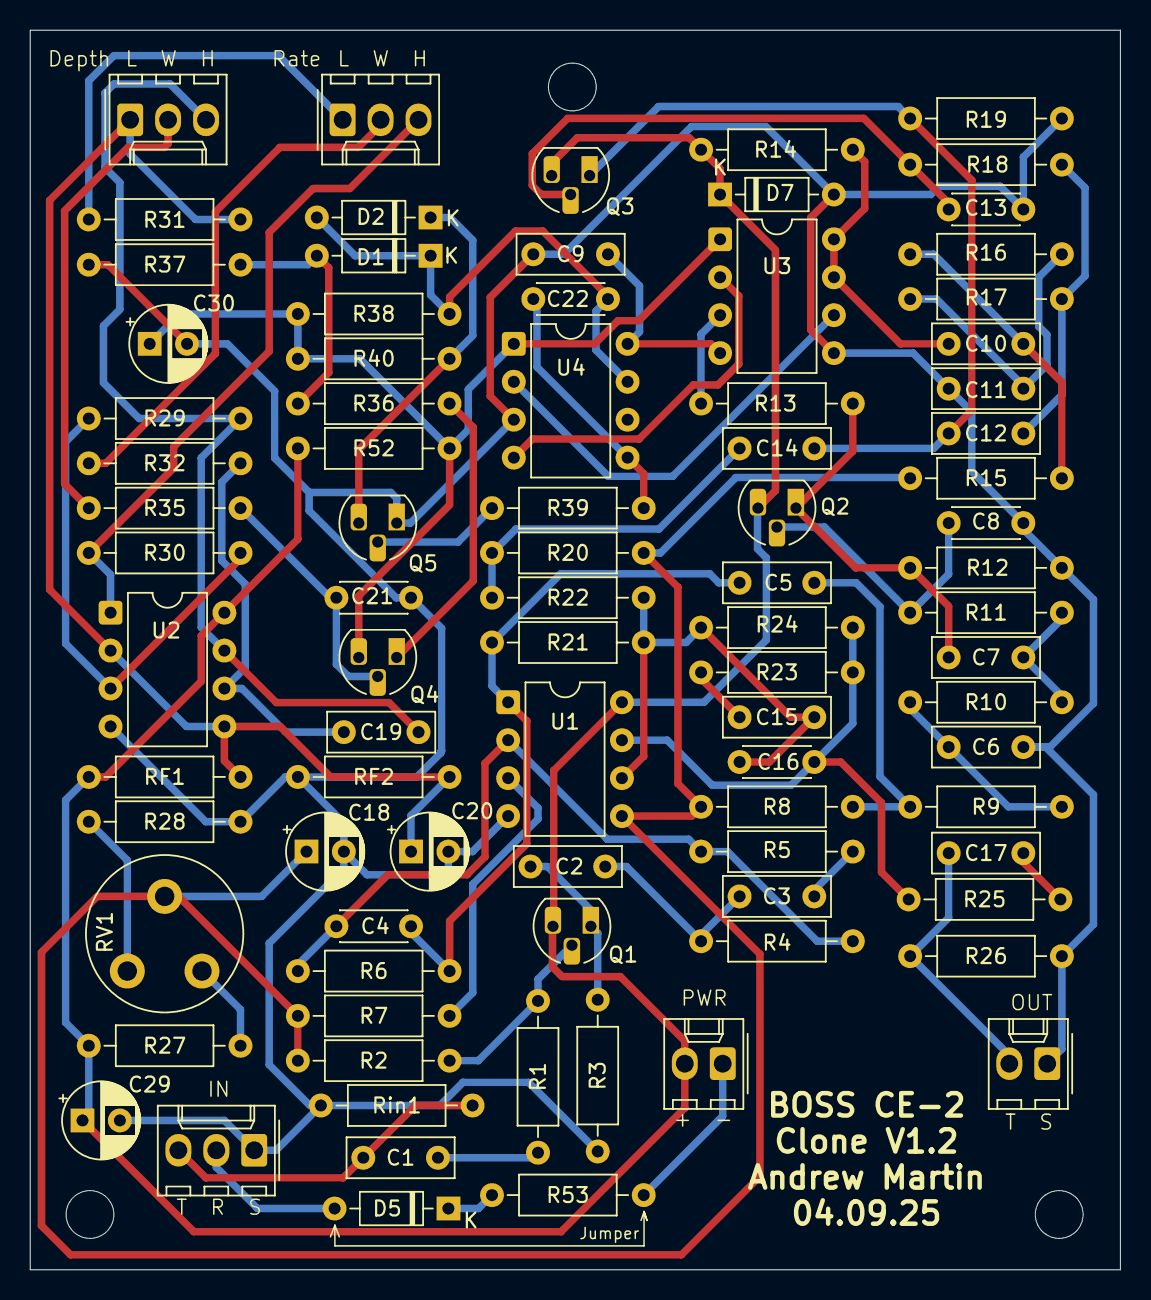
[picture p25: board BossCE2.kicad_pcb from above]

Board: 2 copper layers, 73.0 x 83.0 mm, 86 parts (0 on the bottom side), 54 nets.
